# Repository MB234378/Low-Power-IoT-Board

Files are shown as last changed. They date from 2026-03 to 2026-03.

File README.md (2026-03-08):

Board Specifications:
 - 4 layers (Signal, GND, 3v3, Signal)
 - STM32L051 MCu
 - CC2500 rf transceiver
 - PCB antenna (see TI documentation SWRA118, DN035 for more info on PCB antennas)

Please note that this board is untested as of yet.

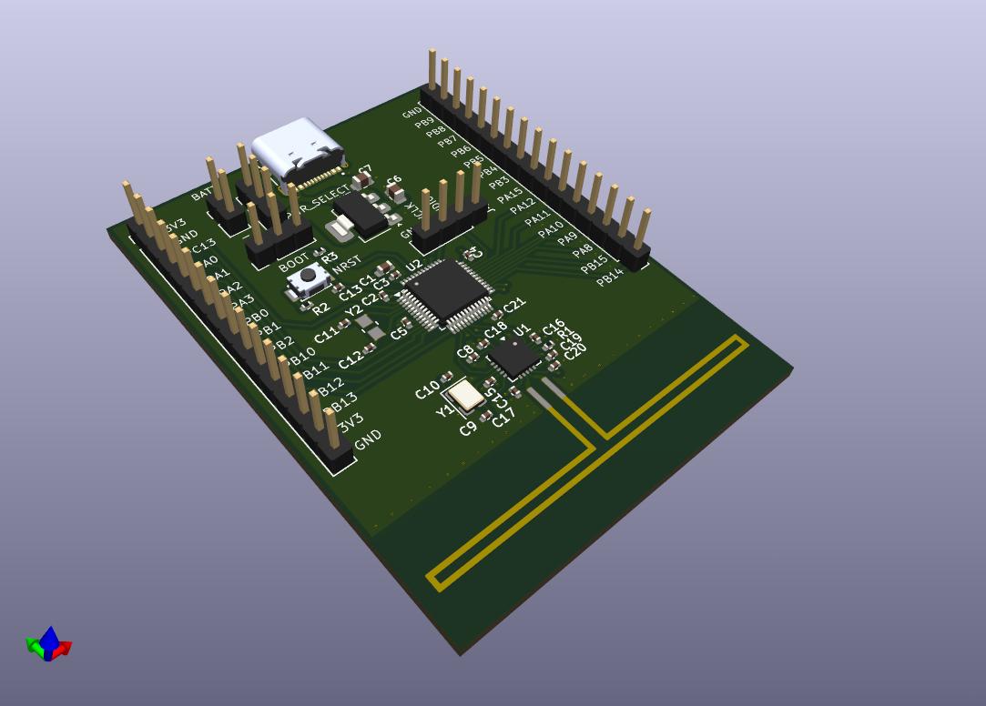
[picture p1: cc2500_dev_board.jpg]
image alt


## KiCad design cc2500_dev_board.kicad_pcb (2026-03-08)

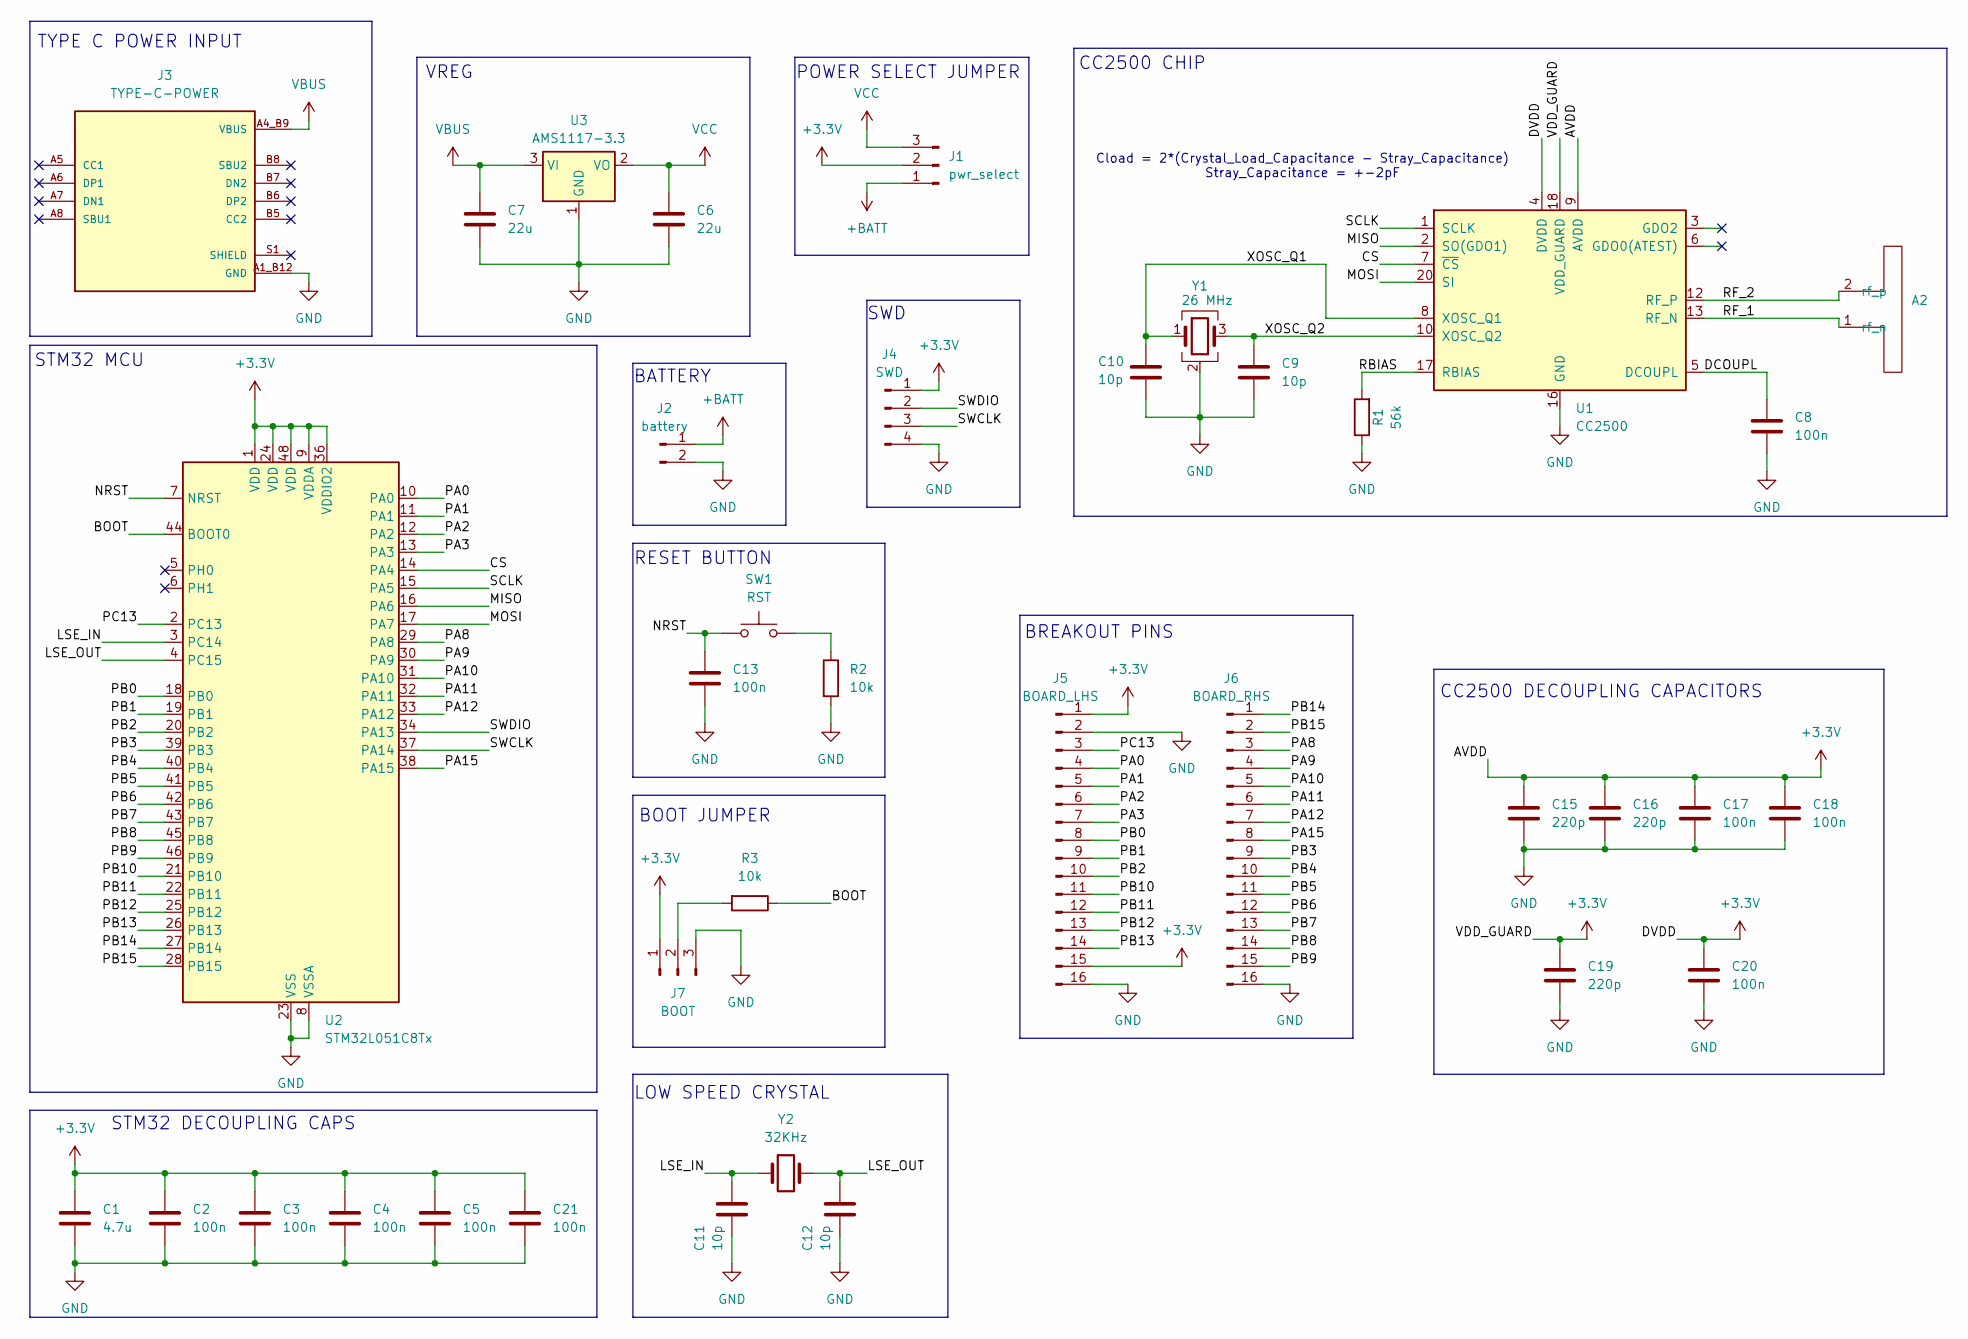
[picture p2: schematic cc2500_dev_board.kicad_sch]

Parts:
A2: FOLDED_DIPOLE_2.4
C1: 4.7u; C_0603_1608Metric
C2, C3, C4, C5, C8, C13, C17, C18, C20, C21: 100n; C_0402_1005Metric
C6, C7: 22u; C_0805_2012Metric
C9, C10, C11, C12: 10p; C_0402_1005Metric
C15, C16, C19: 220p; C_0402_1005Metric
J1: pwr_select; PinHeader_1x03_P2.54mm_Vertical
J2: battery; PinHeader_1x02_P2.54mm_Vertical
J3: TYPE-C-POWER; TYPE_C; PARTREV 2020.12.08
J4: SWD; PinHeader_1x04_P2.54mm_Vertical
J5: BOARD_LHS; PinHeader_1x16_P2.54mm_Vertical
J6: BOARD_RHS; PinHeader_1x16_P2.54mm_Vertical
J7: BOOT; PinHeader_1x03_P2.54mm_Vertical
R1: 56k; R_0402_1005Metric
R2, R3: 10k; R_0402_1005Metric
SW1: RST; Button_SMD
U1: CC2500; Texas_RGP0020H_VQFN-20-1EP_4x4mm_P0.5mm_EP2.4x2.4mm
U2: STM32L051C8Tx; LQFP-48_7x7mm_P0.5mm
U3: AMS1117-3.3; SOT-223-3_TabPin2
Y1: 26 MHz; Crystal_SMD_3225-4Pin_3.2x2.5mm
Y2: 32KHz; XTAL_FC-135_EPS

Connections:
+3.3V: C1.1, C2.1, C3.1, C4.1, C5.1, C15.1, C16.1, C17.1, C18.1, C19.1, C20.1, C21.1, J1.2, J4.1, J5.1, J5.15, J7.1, U1.4 (DVDD), U1.9 (AVDD), U1.11 (AVDD), U1.14 (AVDD), U1.15 (AVDD), U1.18 (VDD_GUARD), U2.1 (VDD), U2.9 (VDDA), U2.24 (VDD), U2.36 (VDDIO2), U2.48 (VDD)
+BATT: J1.1, J2.1
/BOOT: R3.1, U2.44 (BOOT0)
/CS: U1.7 (~CS), U2.14 (PA4)
/DCOUPL: C8.1, U1.5 (DCOUPL)
/LSE_IN: C11.2, U2.3 (PC14), Y2.1
/LSE_OUT: C12.2, U2.4 (PC15), Y2.2
/MISO: U1.2 (SO(GDO1)), U2.16 (PA6)
/MOSI: U1.20 (SI), U2.17 (PA7)
/NRST: C13.1, SW1.1, U2.7 (NRST)
/PA0: J5.4, U2.10 (PA0)
/PA1: J5.5, U2.11 (PA1)
/PA2: J5.6, U2.12 (PA2)
/PA3: J5.7, U2.13 (PA3)
/PA8: J6.3, U2.29 (PA8)
/PA9: J6.4, U2.30 (PA9)
/PA10: J6.5, U2.31 (PA10)
/PA11: J6.6, U2.32 (PA11)
/PA12: J6.7, U2.33 (PA12)
/PA15: J6.8, U2.38 (PA15)
/PB0: J5.8, U2.18 (PB0)
/PB1: J5.9, U2.19 (PB1)
/PB2: J5.10, U2.20 (PB2)
/PB3: J6.9, U2.39 (PB3)
/PB4: J6.10, U2.40 (PB4)
/PB5: J6.11, U2.41 (PB5)
/PB6: J6.12, U2.42 (PB6)
/PB7: J6.13, U2.43 (PB7)
/PB8: J6.14, U2.45 (PB8)
/PB9: J6.15, U2.46 (PB9)
/PB10: J5.11, U2.21 (PB10)
/PB11: J5.12, U2.22 (PB11)
/PB12: J5.13, U2.25 (PB12)
/PB13: J5.14, U2.26 (PB13)
/PB14: J6.1, U2.27 (PB14)
/PB15: J6.2, U2.28 (PB15)
/PC13: J5.3, U2.2 (PC13)
/RBIAS: R1.2, U1.17 (RBIAS)
/RF_1: A2.1 (rf_n), U1.13 (RF_N)
/RF_2: A2.2 (rf_p), U1.12 (RF_P)
/SCLK: U1.1 (SCLK), U2.15 (PA5)
/SWCLK: J4.3, U2.37 (PA14)
/SWDIO: J4.2, U2.34 (PA13)
/XOSC_Q1: C10.1, U1.8 (XOSC_Q1), Y1.1
/XOSC_Q2: C9.1, U1.10 (XOSC_Q2), Y1.3
GND: C1.2, C2.2, C3.2, C4.2, C5.2, C6.2, C7.2, C8.2, C9.2, C10.2, C11.1, C12.1, C13.2, C15.2, C16.2, C17.2, C18.2, C19.2, C20.2, C21.2, J2.2, J3.A1_B12 (GND), J3.B1_A12 (GND), J4.4, J5.2, J5.16, J6.16, J7.3, R1.1, R2.2, U1.16 (GND), U1.19 (GND), U1.21 (GND), U2.8 (VSSA), U2.23 (VSS), U2.35 (VSS), U2.47 (VSS), U3.1 (GND), Y1.2 (G), Y1.4 (G)
unnamed: J7.2, R3.2
unnamed: R2.1, SW1.2
VBUS: C7.1, J3.A4_B9 (VBUS), J3.B4_A9 (VBUS), U3.3 (VI)
VCC: C6.1, J1.3, U3.2 (VO)

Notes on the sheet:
RESET BUTTON
VREG
TYPE C POWER INPUT
BREAKOUT PINS
STM32 MCU
SWD
LOW SPEED CRYSTAL
STM32 DECOUPLING CAPS
BOOT JUMPER
POWER SELECT JUMPER
BATTERY
Cload = 2*(Crystal_Load_Capacitance - Stray_Capacitance) Stray_Capacitance = +-2pF
CC2500 CHIP
CC2500 DECOUPLING CAPACITORS

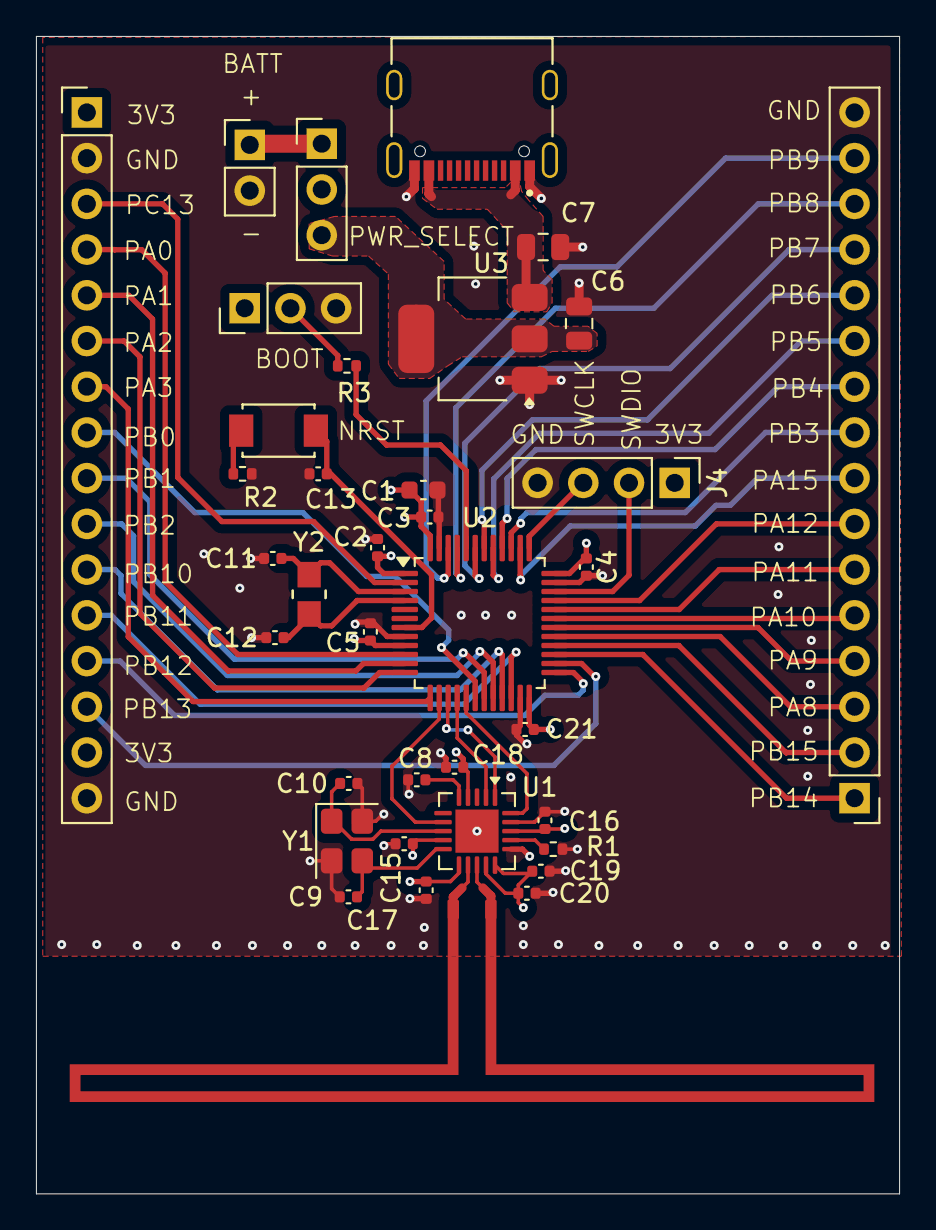
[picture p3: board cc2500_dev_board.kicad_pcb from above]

Board: 4 copper layers, 47.9 x 64.3 mm, 37 parts (0 on the bottom side), 50 nets.
